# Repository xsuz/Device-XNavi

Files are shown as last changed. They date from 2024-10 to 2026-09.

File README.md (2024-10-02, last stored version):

# Device-Template

> A template for building applications for Twelite

This project is developed and maintained by the xsuz

## Dependencies

To build embedded programs using this template you'll need:

- KiCad Version: 8.0.0, or a newer version.

- Git client

- Github CLI (optional)

## Using this template with GitHub CLI

```sh
gh repo create ${repo name} --private --template https://github.com/xsuz/Device-Template -c
cd ${repo name}
sh ./setup.sh
```

注. 自分のアカウントにRepositoryが作られます。

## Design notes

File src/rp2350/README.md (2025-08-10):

# Raspberry Pi Pico2's firmware

## How to build

1. Install PlatformIO
    - Follow the instructions at https://platformio.org/install/ide?install=vscode

2. Install RP2350 board support
    - Open the PlatformIO extension in Visual Studio Code.
    - Go to the "Platforms" tab.
    - Click on "Advanced Installation" and enter the following URL:
      ```
      https://github.com/maxgerhardt/platform-raspberrypi.git
      ```
    - Click "Install" to install the RP2350 board support.

3. Open this directory in Visual Studio Code

4. Build the firmware
    - Press `Ctrl + Alt + B` to build the firmware.

5. Upload the firmware
    - Connect your Raspberry Pi Pico2 to your computer.
    - Press `Ctrl + Alt + U` to upload the firmware.

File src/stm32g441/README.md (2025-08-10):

# STM32G4's firmware

## How to build

1. Install make utilities
    ```
    sudo apt install build-essential
    ```
1. Install Arm GNU Toolchain
    ```bash
    sudo apt install gcc-arm-none-eabi
    ```
1. Run `make` command in this directory

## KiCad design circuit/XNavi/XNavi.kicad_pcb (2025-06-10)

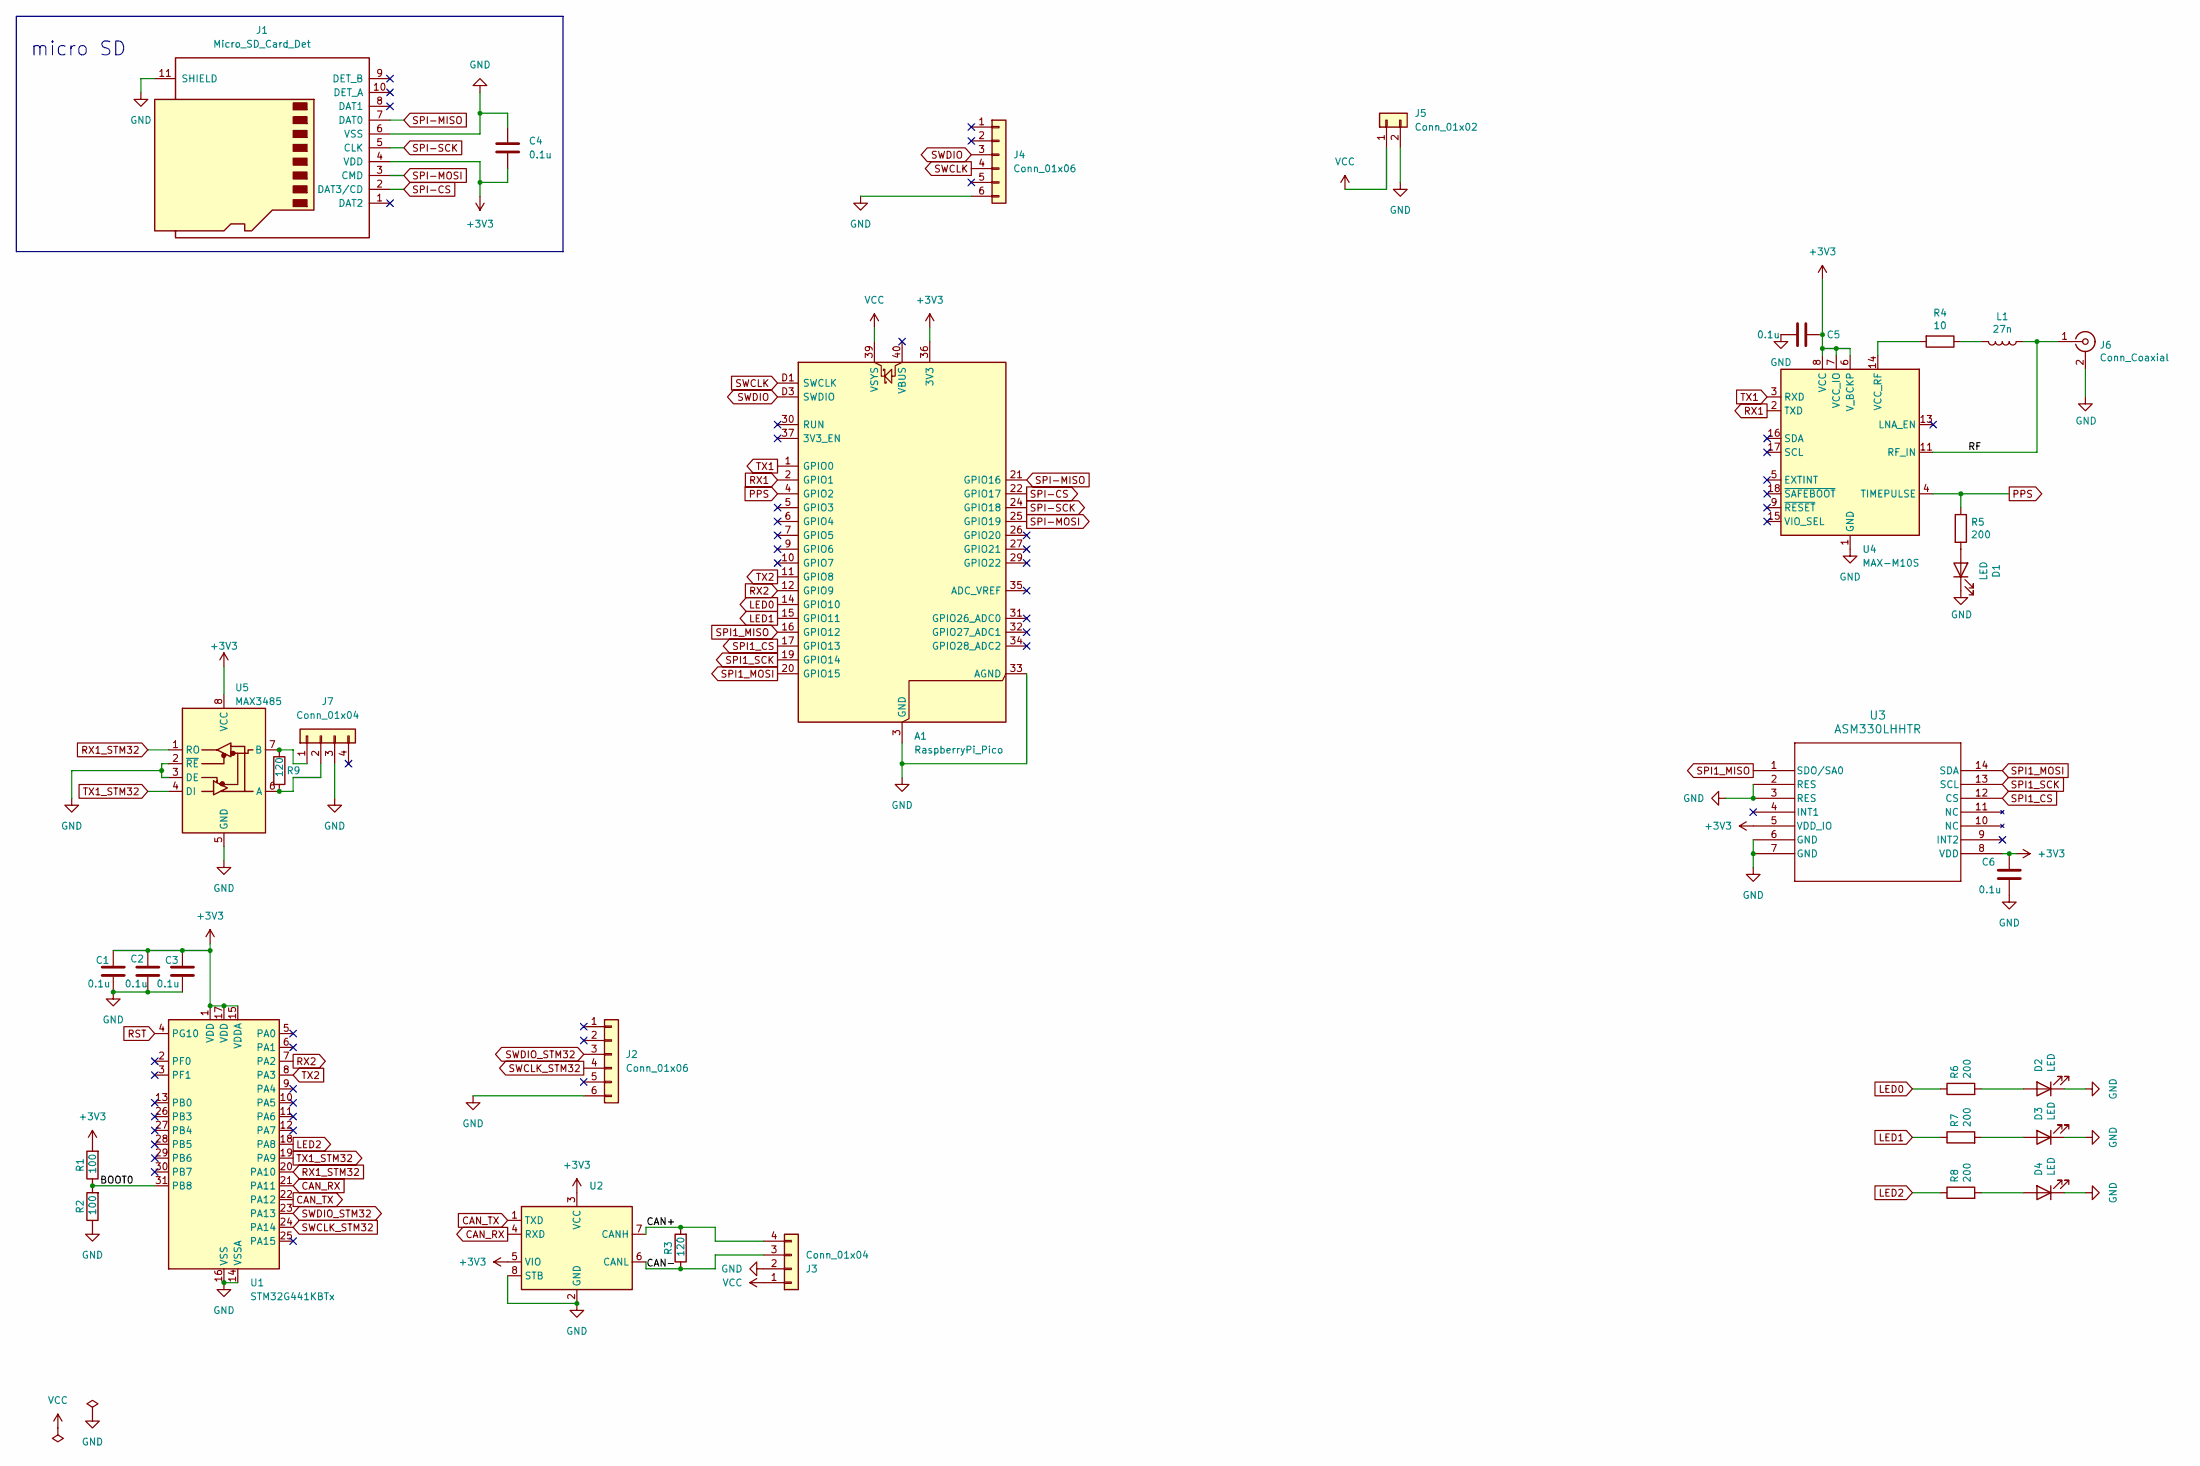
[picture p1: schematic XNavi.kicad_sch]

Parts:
A1: RaspberryPi_Pico; RaspberryPi_Pico_SMD_HandSolder
C1, C2, C3, C4, C5, C6: 0.1u; C_0603_1608Metric_Pad1.08x0.95mm_HandSolder
D1, D2, D3, D4: LED; D_0603_1608Metric_Pad1.05x0.95mm_HandSolder
J1: Micro_SD_Card_Det; microSD_HC_Hirose_DM3AT-SF-PEJM5
J2, J4: Conn_01x06; JST_ZH_B6B-ZR_1x06_P1.50mm_Vertical
J3, J7: Conn_01x04; JST_PH_S4B-PH-SM4-TB_1x04-1MP_P2.00mm_Horizontal
J5: Conn_01x02; JST_PH_S2B-PH-SM4-TB_1x02-1MP_P2.00mm_Horizontal
J6: Conn_Coaxial; U.FL_Molex_MCRF_73412-0110_Vertical
L1: 27n; L_0805_2012Metric_Pad1.15x1.40mm_HandSolder
R1, R2: 100; R_0603_1608Metric_Pad0.98x0.95mm_HandSolder
R3, R9: 120; R_0603_1608Metric_Pad0.98x0.95mm_HandSolder
R4: 10; R_0603_1608Metric_Pad0.98x0.95mm_HandSolder
R5, R6, R7, R8: 200; R_0603_1608Metric_Pad0.98x0.95mm_HandSolder
U1: STM32G441KBTx; LQFP-32_7x7mm_P0.8mm
U2: SOT-23-8_Handsoldering
U3: ASM330LHHTR; LGA-14_3x2.5mm_P0.5mm_LayoutBorder3x4y
U4: MAX-M10S; ublox_MAX
U5: MAX3485; SOP-8_3.76x4.96mm_P1.27mm

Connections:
+3V3: A1.36 (3V3), C1.1, C2.1, C3.1, C4.2, C5.1, C6.1, J1.4 (VDD), R1.2, U1.1 (VDD), U1.15 (VDDA), U1.17 (VDD), U2.3 (VCC), U2.5 (VIO), U3.5 (VDD_IO), U3.8 (VDD), U4.6 (V_BCKP), U4.7 (VCC_IO), U4.8 (VCC), U5.8 (VCC)
/BOOT0: R1.1, R2.2, U1.31 (PB8)
/CAN+: J3.4, R3.2, U2.7 (CANH)
/CAN-: J3.3, R3.1, U2.6 (CANL)
/RF: J6.1 (In), L1.1, U4.11 (RF_IN)
CAN_RX: U1.21 (PA11), U2.4 (RXD)
CAN_TX: U1.22 (PA12), U2.1 (TXD)
GND: A1.3 (GND), A1.8 (GND), A1.13 (GND), A1.18 (GND), A1.23 (GND), A1.28 (GND), A1.33 (AGND), A1.38 (GND), A1.D2 (GND), C1.2, C2.2, C3.2, C4.1, C5.2, C6.2, D1.1 (K), D2.1 (K), D3.1 (K), D4.1 (K), J1.6 (VSS), J1.11 (SHIELD), J2.6, J3.2, J4.6, J5.2, J6.2 (Ext), J7.3, R2.1, U1.14 (VSSA), U1.16 (VSS), U1.32 (VSS), U2.2 (GND), U2.8 (STB), U3.2 (RES), U3.3 (RES), U3.6 (GND), U3.7 (GND), U4.1 (GND), U4.10 (GND), U4.12 (GND), U5.2 (~RE), U5.3 (DE), U5.5 (GND)
LED0: A1.14 (GPIO10), R6.1
LED1: A1.15 (GPIO11), R7.1
LED2: R8.1, U1.18 (PA8)
unnamed: D1.2 (A), R5.2
unnamed: D2.2 (A), R6.2
unnamed: D3.2 (A), R7.2
unnamed: D4.2 (A), R8.2
unnamed: J7.1, R9.1, U5.7 (B)
unnamed: J7.2, R9.2, U5.6 (A)
unnamed: L1.2, R4.1
unnamed: R4.2, U4.14 (VCC_RF)
PPS: A1.4 (GPIO2), R5.1, U4.4 (TIMEPULSE)
RST: U1.4 (PG10)
RX1: A1.2 (GPIO1), U4.2 (TXD)
RX1_STM32: U1.20 (PA10), U5.1 (RO)
RX2: A1.12 (GPIO9), U1.7 (PA2)
SPI1_CS: A1.17 (GPIO13), U3.12 (CS)
SPI1_MISO: A1.16 (GPIO12), U3.1 (SDO/SA0)
SPI1_MOSI: A1.20 (GPIO15), U3.14 (SDA)
SPI1_SCK: A1.19 (GPIO14), U3.13 (SCL)
SPI-CS: A1.22 (GPIO17), J1.2 (DAT3/CD)
SPI-MISO: A1.21 (GPIO16), J1.7 (DAT0)
SPI-MOSI: A1.25 (GPIO19), J1.3 (CMD)
SPI-SCK: A1.24 (GPIO18), J1.5 (CLK)
SWCLK: A1.D1 (SWCLK), J4.4
SWCLK_STM32: J2.4, U1.24 (PA14)
SWDIO: A1.D3 (SWDIO), J4.3
SWDIO_STM32: J2.3, U1.23 (PA13)
TX1: A1.1 (GPIO0), U4.3 (RXD)
TX1_STM32: U1.19 (PA9), U5.4 (DI)
TX2: A1.11 (GPIO8), U1.8 (PA3)
VCC: A1.39 (VSYS), J3.1, J5.1

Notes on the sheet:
micro SD

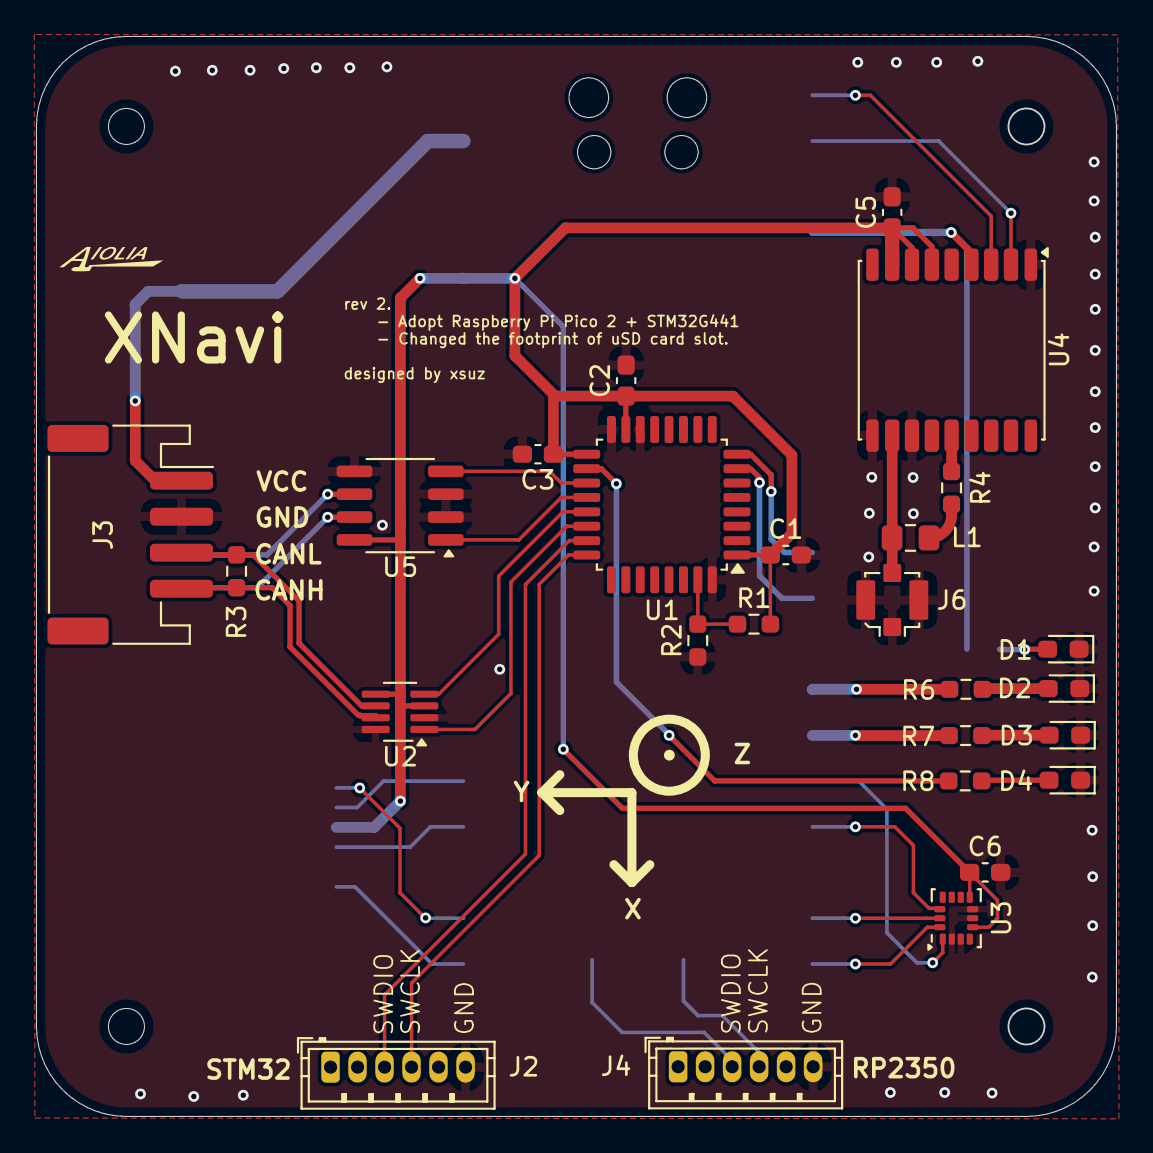
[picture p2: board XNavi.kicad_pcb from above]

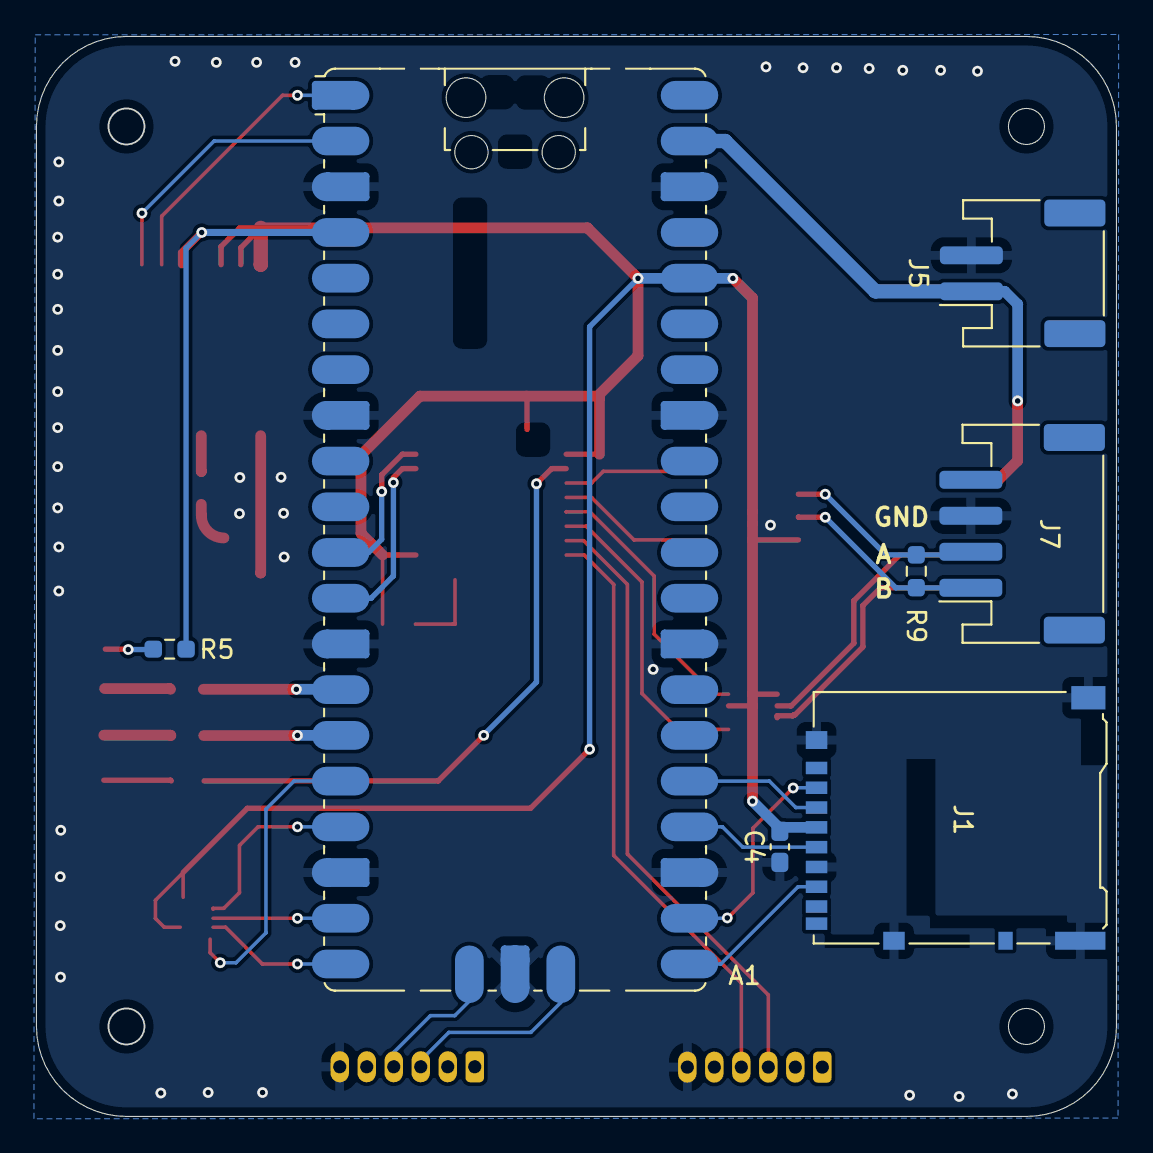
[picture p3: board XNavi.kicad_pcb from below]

Board: 2 copper layers, 60.0 x 60.0 mm, 33 parts (7 on the bottom side), 39 nets.

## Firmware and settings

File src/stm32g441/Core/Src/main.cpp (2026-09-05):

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
/* Includes ------------------------------------------------------------------*/
#include "main.h"
#include "cmsis_os.h"
#include "dma.h"
#include "fdcan.h"
#include "usart.h"
#include "gpio.h"

/* USER CODE BEGIN Includes */
#include <SEGGER_RTT.h>
/* USER CODE END Includes */

/* USER CODE BEGIN PD */

void MX_FREERTOS_Init(void);

/* USER CODE END PD */


void SystemClock_Config(void);
void MX_FREERTOS_Init(void);
/**
  * @brief  The application entry point.
  * @retval int
  */
int main(void)
{

  /* USER CODE BEGIN 1 */
	// SEGGER_RTT_Init();
  /* USER CODE END 1 */

  /* MCU Configuration--------------------------------------------------------*/

  /* Reset of all peripherals, Initializes the Flash interface and the Systick. */
  HAL_Init();

  /* USER CODE BEGIN Init */
	SEGGER_RTT_printf(0,"program started\n");
  /* USER CODE END Init */

  /* Configure the system clock */
  SystemClock_Config();

  /* USER CODE BEGIN SysInit */

  HAL_Delay(2000);

  /* USER CODE END SysInit */

  /* Initialize all configured peripherals */
  MX_GPIO_Init();
  MX_DMA_Init();
  MX_FDCAN1_Init();
  MX_USART2_UART_Init();
  /* USER CODE BEGIN 2 */

	if (HAL_FDCAN_Start(&hfdcan1) != HAL_OK)
	{
		Error_Handler();
	}

	// Activate the notification for new data in FIFO0 for FDCAN1
	if (HAL_FDCAN_ActivateNotification(&hfdcan1, FDCAN_IT_RX_FIFO0_NEW_MESSAGE, 0) != HAL_OK)
	{
		Error_Handler();
	}

  /* USER CODE END 2 */

  /* Init scheduler */
  osKernelInitialize();

  /* Call init function for freertos objects (in cmsis_os2.c) */
  MX_FREERTOS_Init();

  /* Start scheduler */
  vTaskStartScheduler();

  /* We should never get here as control is now taken by the scheduler */

  /* Infinite loop */
  /* USER CODE BEGIN WHILE */
  while (1)
  {
    /* USER CODE END WHILE */

    /* USER CODE BEGIN 3 */
  }
  /* USER CODE END 3 */
}

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
/**
  * @brief  Period elapsed callback in non blocking mode
  * @note   This function is called  when TIM17 interrupt took place, inside
  * HAL_TIM_IRQHandler(). It makes a direct call to HAL_IncTick() to increment
  * a global variable "uwTick" used as application time base.
  * @param  htim : TIM handle
  * @retval None
  */
void HAL_TIM_PeriodElapsedCallback(TIM_HandleTypeDef *htim)
{
  if (htim->Instance == TIM17)
  {
    HAL_IncTick();
  }
}

/**
  * @brief  This function is executed in case of error occurrence.
  * @retval None
  */
void Error_Handler(void)
{
  /* USER CODE BEGIN Error_Handler_Debug */
  /* User can add his own implementation to report the HAL error return state */
  __disable_irq();
  while (1)
  {
  }
  /* USER CODE END Error_Handler_Debug */
}

#ifdef  USE_FULL_ASSERT
/**
  * @brief  Reports the name of the source file and the source line number
  *         where the assert_param error has occurred.
  * @param  file: pointer to the source file name
  * @param  line: assert_param error line source number
  * @retval None
  */
void assert_failed(uint8_t *file, uint32_t line)
{
  /* USER CODE BEGIN 6 */
  /* User can add his own implementation to report the file name and line number,
     ex: printf("Wrong parameters value: file %s on line %d\r\n", file, line) */
  /* USER CODE END 6 */
}
#endif /* USE_FULL_ASSERT */

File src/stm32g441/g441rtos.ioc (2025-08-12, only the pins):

Mcu.UserName=STM32G441KBTx
PA11.Signal=FDCAN1_RX
PA12.Signal=FDCAN1_TX
PA13.Signal=SYS_JTMS-SWDIO
PA14.Signal=SYS_JTCK-SWCLK
PA2.Signal=USART2_TX
PA3.Signal=USART2_RX
PA8.GPIO_Label=LED
PA8.Signal=GPIO_Output

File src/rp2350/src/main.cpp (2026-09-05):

#include <Arduino.h>
#include <FreeRTOS.h>
#include <task.h>
#include <map>

#include <SEGGER_RTT.h>

#include "microsd.h"
#include "gnss.h"
#include "imu.h"
#include "canbus.h"
#include "monitor.h"
#include "clock.h"
#include "config.hpp"

Subscriber usd_subscriber(100);
Subscriber canbus_subscriber(10);
uSDTask usd_task(usd_subscriber);
IMUTask imu_task;
GNSSTask gnss_task;
MonitorTask monitor_task;
CANBusTask canbus_task(canbus_subscriber);

void setup()
{
    // put your setup code here, to run once:
    SEGGER_RTT_Init();
    SEGGER_RTT_printf(0, "\n[%sINFO%s root] : power on\n", RTT_CTRL_TEXT_GREEN, RTT_CTRL_RESET);

    imu_task.add_subscriber(usd_subscriber);
    monitor_task.add_subscriber(usd_subscriber);
    gnss_task.add_subscriber(usd_subscriber);

    // imu_task.add_subscriber(canbus_subscriber);
    monitor_task.add_subscriber(canbus_subscriber);
    gnss_task.add_subscriber(canbus_subscriber);

    imu_task.start();
    monitor_task.start();
    gnss_task.start();
    usd_task.start();
    canbus_task.start();
    // vTaskStartScheduler();
}

void loop()
{
    // put your main code here, to run repeatedly:
    mavlink_message_t msg;
    mavlink_heartbeat_t heartbeat;
    heartbeat.autopilot = MAV_AUTOPILOT::MAV_AUTOPILOT_GENERIC;
    heartbeat.base_mode = MAV_MODE::MAV_MODE_PREFLIGHT;
    heartbeat.custom_mode = 0;
    heartbeat.mavlink_version = 3;
    heartbeat.system_status = MAV_STATE::MAV_STATE_ACTIVE;
    heartbeat.type = MAV_TYPE::MAV_TYPE_GENERIC;
    mavlink_msg_heartbeat_encode(config::mavlink::system_id, config::mavlink::component_id, &msg, &heartbeat);
    canbus_subscriber.push(msg,sys_clock::get_timestamp());
    vTaskDelay(1000);
}

// std::map<eTaskState, const char *> eTaskStateName { {eReady, "Ready"}, { eRunning, "Running" }, {eBlocked, "Blocked"}, {eSuspended, "Suspended"}, {eDeleted, "Deleted"} };

void setup1()
{

    // TWELITEのUARTを初期化
    pinMode(LED_BUILTIN, OUTPUT);
}

void loop1()
{
    // int tasks = uxTaskGetNumberOfTasks();
    // unsigned long runtime;
    // TaskStatus_t *pxTaskStatusArray= (TaskStatus_t *) pvPortMalloc(tasks * sizeof(TaskStatus_t));
    // tasks = uxTaskGetSystemState(pxTaskStatusArray, tasks, &runtime);
    // SEGGER_RTT_printf(0,"Tasks: %d\n",tasks);
    // for(int i=0;i<tasks;i++){
    //     SEGGER_RTT_printf(0,"    %d: %-20s %-10s %d %lu\n", i, pxTaskStatusArray[i].pcTaskName, eTaskStateName[pxTaskStatusArray[i].eCurrentState], (int)pxTaskStatusArray[i].uxCurrentPriority, pxTaskStatusArray[i].ulRunTimeCounter);
    // }
    // vPortFree(pxTaskStatusArray);

    digitalWrite(LED_BUILTIN, HIGH);
    vTaskDelay(500 / portTICK_PERIOD_MS);
    digitalWrite(LED_BUILTIN, LOW);
    vTaskDelay(500 / portTICK_PERIOD_MS);
}

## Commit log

2025-01-09 回路図&PCBを追加
    [XNavi.kicad_pcb, XNavi.kicad_sch]
2025-04-25 TCR3UF33Aを追加
2025-05-22 MCUをRaspberry Pi Pico(2)に変更
    [XNavi.kicad_pcb, XNavi.kicad_sch]
2025-05-29 RS485追加 & シルク追加
    [XNavi.kicad_pcb, XNavi.kicad_sch]
2025-06-10 UARTの信号線変更,基板を発注
    [XNavi.kicad_pcb, XNavi.kicad_sch]
2025-07-13 rp2350のプログラムを追加
2025-07-18 stm32g441のプログラムを追加
2025-07-18 SEGGER_RTTでログを吐き出す
2025-07-19 Queueを介してIMUDataを渡すようにした
2025-07-27 時刻補正の処理をsd_loggerから分離
2025-07-27 CAN busから受信したデータをrp2350に転送する処理を追加
2025-08-05 GPSによる時刻補正が完了するまで待機するようにした
2025-08-05 gnss関連の処理で使っていない変数を消した
2025-08-05 BOOTSELを押している間はログの保存を停止するようにした
2025-08-05 各タスクの優先度を変更
2025-08-06 readmeの内容を変更
2025-08-10 README追加
2025-08-10 Raspberry Pi Pico2内蔵のADCでVCCの電圧を取得するようにした．
2025-08-11 LEDの仕様を変更
2025-08-11 ubxのエラーハンドリングの改良 電池残量を推定
2025-08-12 cppに対応
2025-08-12 名前空間で囲った
2025-08-12 RP2350-STM32G441間で双方向に通信できるようにした
2025-08-12 FDCANを使うことにした
2025-08-12 STM32側にCOBSの処理をする時間を与えた
2025-08-12 stm32の起動を遅らせてcobsが正常に動くようにした
2025-08-13 XNavi内部とCAN busではLittle Endianで統一することに決定
2025-08-13 FDCANで送信できるようにする cobsのoverflowに対応
2025-08-15 FDCANで12byte以上のサイズのデータを受信できない問題を解決
2025-08-20 clockとFDCANの設定を変更
2025-08-21 RP2350が再起動するとUARTの通信が停止する問題を解決
2025-08-21 RTTのメッセージのフォーマットを定めた
2025-08-24 UARTの送信をDMAを介して行うようにした
2025-08-27 STM32側のbuild systemをCubeMX+CMakeの構成に変更
2025-08-28 vscodeのcmakeとdebug関連の設定を追加
2025-09-01 fatfsを更新
2025-09-01 README修正
2026-01-04 platformの指定方法を変更
2026-01-18 vscodeからrttの出力を見れるようにした
2026-08-15 mavlinkに対応
2026-08-22 task間の通信をqueueにした
2026-08-22 taskの名前を変えた
2026-08-22 Big Endianで時刻を保存させた
2026-08-22 RTTの出力形式を統一した
2026-08-23 consumerという名前をpublisherに対応する言葉であるsubscriberに変更
2026-08-29 mavlinkのdialectを更新
2026-09-05 method名などのrefactoring

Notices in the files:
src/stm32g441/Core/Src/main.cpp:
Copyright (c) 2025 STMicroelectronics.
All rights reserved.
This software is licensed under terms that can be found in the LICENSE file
